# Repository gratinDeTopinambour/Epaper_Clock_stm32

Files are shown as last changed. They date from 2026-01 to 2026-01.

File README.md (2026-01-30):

# Epaper_Clock_display

A silent, light-free bedside clock built with:

- **STM32F103C** (“Blue Pill”)
- **ESP-01** (Wi‑Fi)
- **3.52" e-paper HAT (B)**
- **BME280** (temperature, humidity, pressure sensor)

No display backlight, no ticking noise – ideal to keep next to your bed without disturbing sleep.

---

## Features

- **Always-readable e-paper display**
  - Time and date
  - Temperature, humidity (BME280)
- **Low light pollution**
  - E-paper only refreshes when needed
  - No LEDs or backlight by default
- **Wi‑Fi connectivity (ESP‑01)**
  - Intended for time sync
---

## Project Structure

```text
Epaper_Clock_stm32/
├─ 3D_print/                 # Enclosure and mechanical parts
├─ Electronics and schematics/  # Schematics, PCB files, wiring diagrams
└─ Stm32 Code/               # STM32 firmware (CubeIDE project)
```

- **`3D_print/`**  
  Contains all files related to the case/enclosure:
  - STL files for 3D printing

- **`Electronics and schematics/`**  
  Contains all electronics documentation:
  - Schematics
  - gerber

- **`Stm32 Code/`**  
  STM32CubeIDE project implementing:
  - Display update logic
  - Sensor reading (BME280 via I2C)
  - Interface with ESP‑01 (UART)
  - Timer-based refresh (TIM3, 1‑minute interrupt)  
---

## Hardware Overview

- **MCU**: STM32F103C
- **Display**: 3.52" e-paper HAT (B)
- **Wi‑Fi module**: ESP‑01
- **Sensor**: BME280
- **Power**: 5 V input (e.g. USB), with on-board regulation to 3.3 V for logic

---

## Getting Started

1. **Print the enclosure**  
   - Open `3D_print/` and print the parts

2. **Build the electronics**  
   - Use the schematics and wiring diagrams from `Electronics and schematics/`.

3. **Flash the STM32 firmware**
   - Open the project in **STM32CubeIDE** from the `Stm32 Code/` folder.
   - Check that the pin configuration matches your STM32 variant and board.
   - Build and flash using an ST‑Link.

4. **Assemble the clock**
   - Mount the boards and e‑paper into the printed enclosure.
   - Route cables and ensure no strain on connectors.
   - Close the enclosure.

---

## Future Improvements / Ideas

- Meteo information
- Battery backup

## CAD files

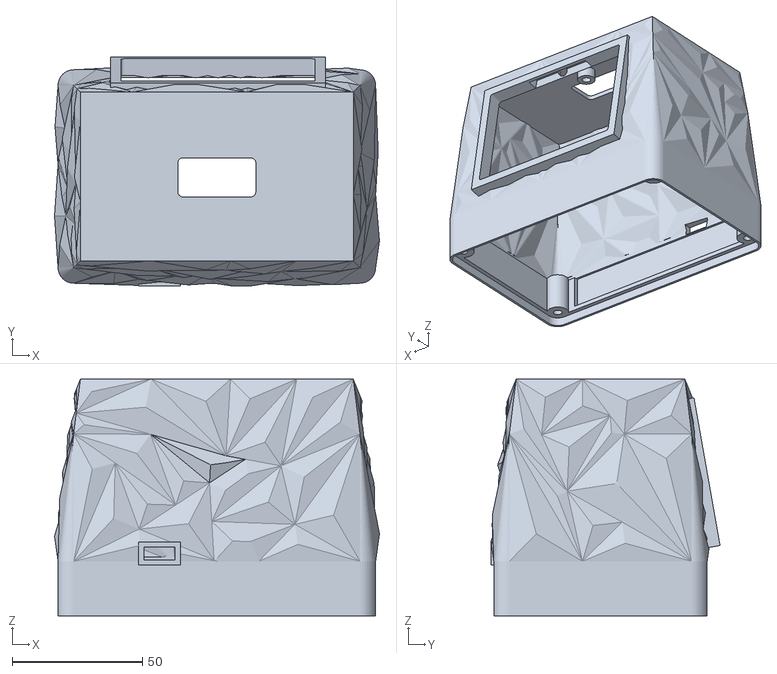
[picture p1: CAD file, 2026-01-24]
3D_print/top_reveil.stl
124.8 x 88.0 x 91.0

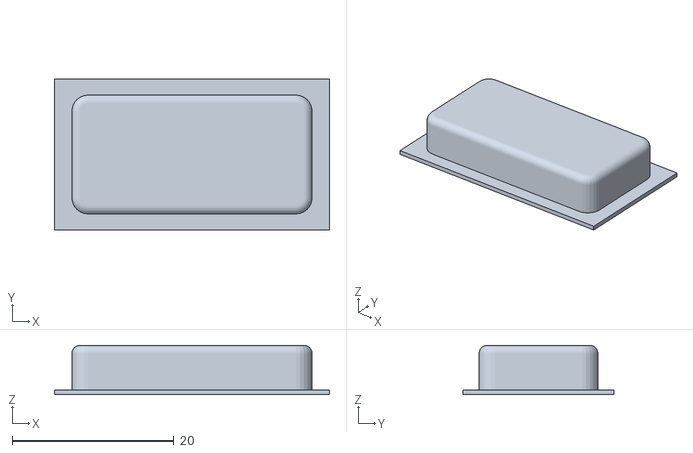
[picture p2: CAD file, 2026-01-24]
3D_print/switch_display.stl
34.0 x 18.7 x 6.10

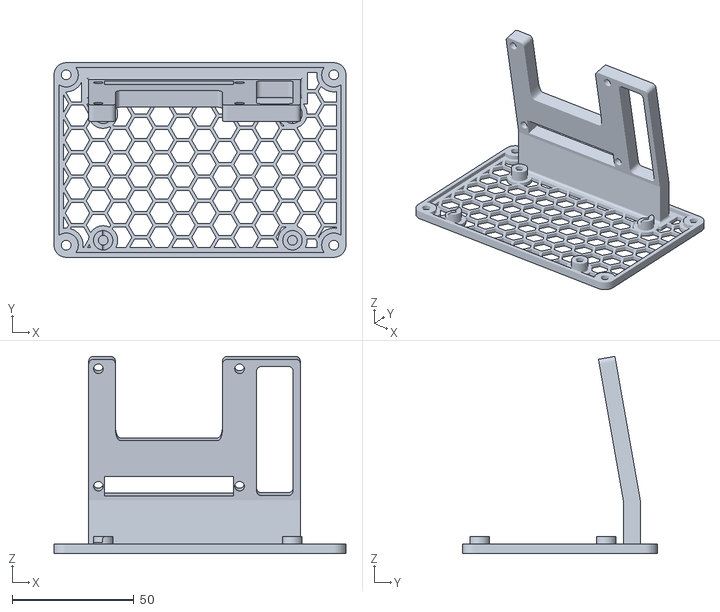
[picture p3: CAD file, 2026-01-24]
3D_print/base_reveil_v2.stl
120.0 x 80.0 x 81.1

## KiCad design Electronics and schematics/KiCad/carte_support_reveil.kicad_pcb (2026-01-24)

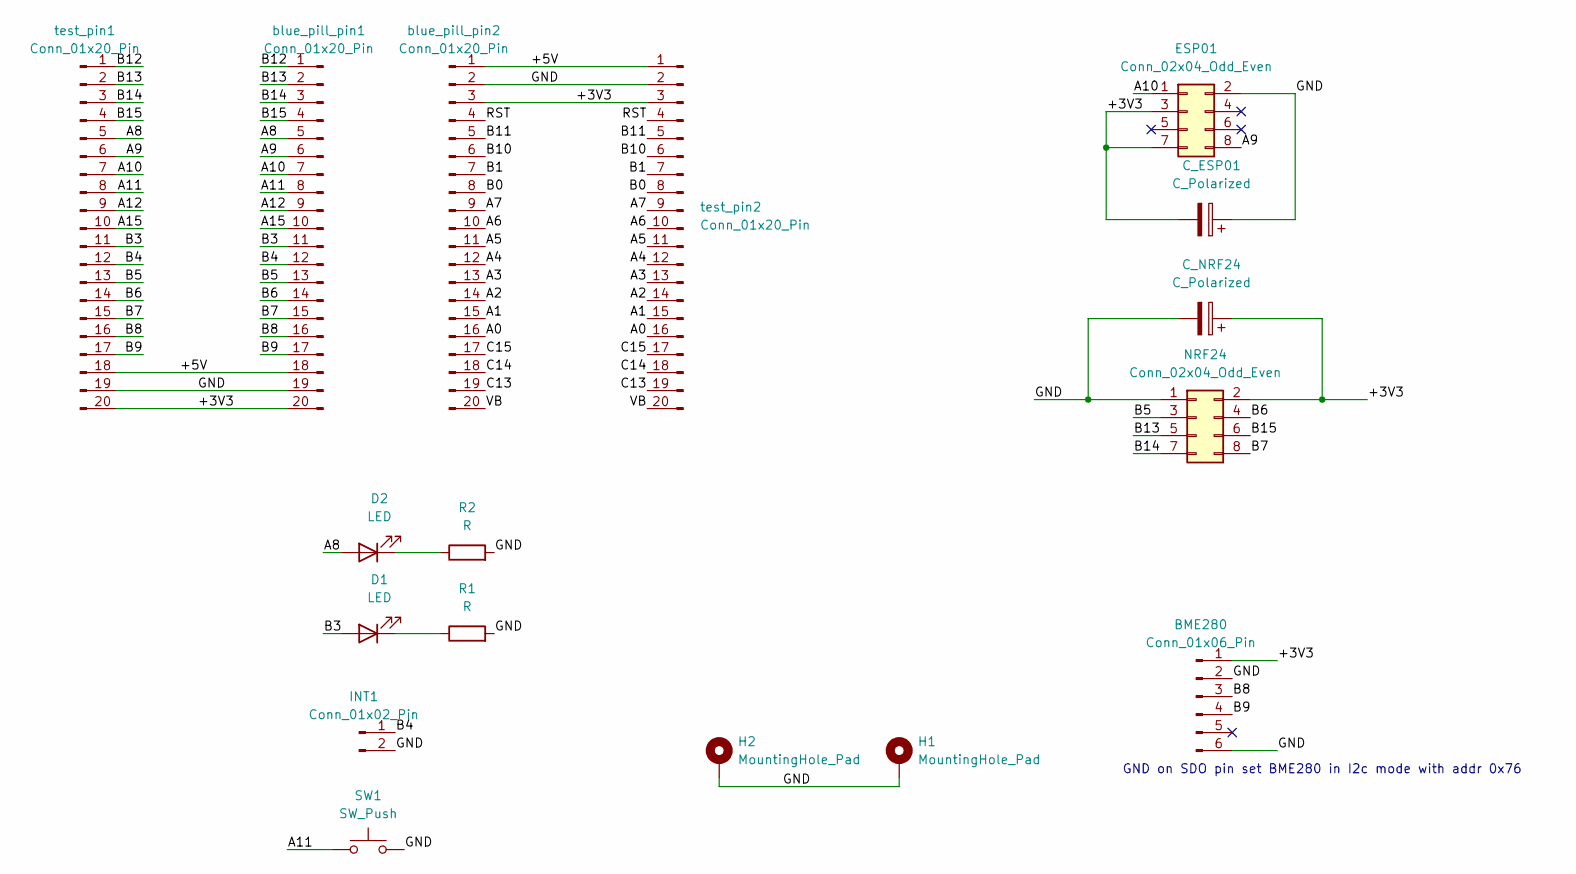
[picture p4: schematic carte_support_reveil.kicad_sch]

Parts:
BME280: Conn_01x06_Pin; PinHeader_1x06_P2.54mm_Vertical
C_ESP01: C_Polarized; C_Radial_D6.3mm_H11.0mm_P2.50mm
C_NRF24: C_Polarized; C_Radial_D6.3mm_H11.0mm_P2.50mm
D1, D2: LED; LED_D5.0mm
ESP01: Conn_02x04_Odd_Even; PinHeader_2x04_P2.54mm_Vertical
H1, H2: MountingHole_Pad; MountingHole_3.2mm_M3_Pad_Via
INT1: Conn_01x02_Pin; PinHeader_1x02_P2.54mm_Vertical
NRF24: Conn_02x04_Odd_Even; PinHeader_2x04_P2.54mm_Vertical
R1, R2: R; R_Axial_DIN0411_L9.9mm_D3.6mm_P15.24mm_Horizontal
SW1: SW_Push; SW_PUSH_6mm_H5mm
blue_pill_pin1, blue_pill_pin2: Conn_01x20_Pin; PinHeader_1x20_P2.54mm_Vertical
test_pin1, test_pin2: Conn_01x20_Pin; PinHeader_1x20_P2.54mm_Vertical

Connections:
/+3V3: BME280.1, C_ESP01.2, C_NRF24.1, ESP01.3, ESP01.7, NRF24.2, blue_pill_pin1.20, blue_pill_pin2.3, test_pin1.20, test_pin2.3
/+5V: blue_pill_pin1.18, blue_pill_pin2.1, test_pin1.18, test_pin2.1
/A0: blue_pill_pin2.16, test_pin2.16
/A1: blue_pill_pin2.15, test_pin2.15
/A2: blue_pill_pin2.14, test_pin2.14
/A3: blue_pill_pin2.13, test_pin2.13
/A4: blue_pill_pin2.12, test_pin2.12
/A5: blue_pill_pin2.11, test_pin2.11
/A6: blue_pill_pin2.10, test_pin2.10
/A7: blue_pill_pin2.9, test_pin2.9
/A8: D2.2 (A), blue_pill_pin1.5, test_pin1.5
/A9: ESP01.8, blue_pill_pin1.6, test_pin1.6
/A10: ESP01.1, blue_pill_pin1.7, test_pin1.7
/A11: SW1.1, blue_pill_pin1.8, test_pin1.8
/A12: blue_pill_pin1.9, test_pin1.9
/A15: blue_pill_pin1.10, test_pin1.10
/B0: blue_pill_pin2.8, test_pin2.8
/B1: blue_pill_pin2.7, test_pin2.7
/B3: D1.2 (A), blue_pill_pin1.11, test_pin1.11
/B4: INT1.1, blue_pill_pin1.12, test_pin1.12
/B5: NRF24.3, blue_pill_pin1.13, test_pin1.13
/B6: NRF24.4, blue_pill_pin1.14, test_pin1.14
/B7: NRF24.8, blue_pill_pin1.15, test_pin1.15
/B8: BME280.3, blue_pill_pin1.16, test_pin1.16
/B9: BME280.4, blue_pill_pin1.17, test_pin1.17
/B10: blue_pill_pin2.6, test_pin2.6
/B11: blue_pill_pin2.5, test_pin2.5
/B12: blue_pill_pin1.1, test_pin1.1
/B13: NRF24.5, blue_pill_pin1.2, test_pin1.2
/B14: NRF24.7, blue_pill_pin1.3, test_pin1.3
/B15: NRF24.6, blue_pill_pin1.4, test_pin1.4
/C13: blue_pill_pin2.19, test_pin2.19
/C14: blue_pill_pin2.18, test_pin2.18
/C15: blue_pill_pin2.17, test_pin2.17
/GND: BME280.2, BME280.6, C_ESP01.1, C_NRF24.2, ESP01.2, H1.1, H2.1, INT1.2, NRF24.1, R1.2, R2.2, SW1.2, blue_pill_pin1.19, blue_pill_pin2.2, test_pin1.19, test_pin2.2
/RST: blue_pill_pin2.4, test_pin2.4
/VB: blue_pill_pin2.20, test_pin2.20
unnamed: D1.1 (K), R1.1
unnamed: D2.1 (K), R2.1

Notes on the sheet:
GND on SDO pin set BME280 in I2c mode with addr 0x76

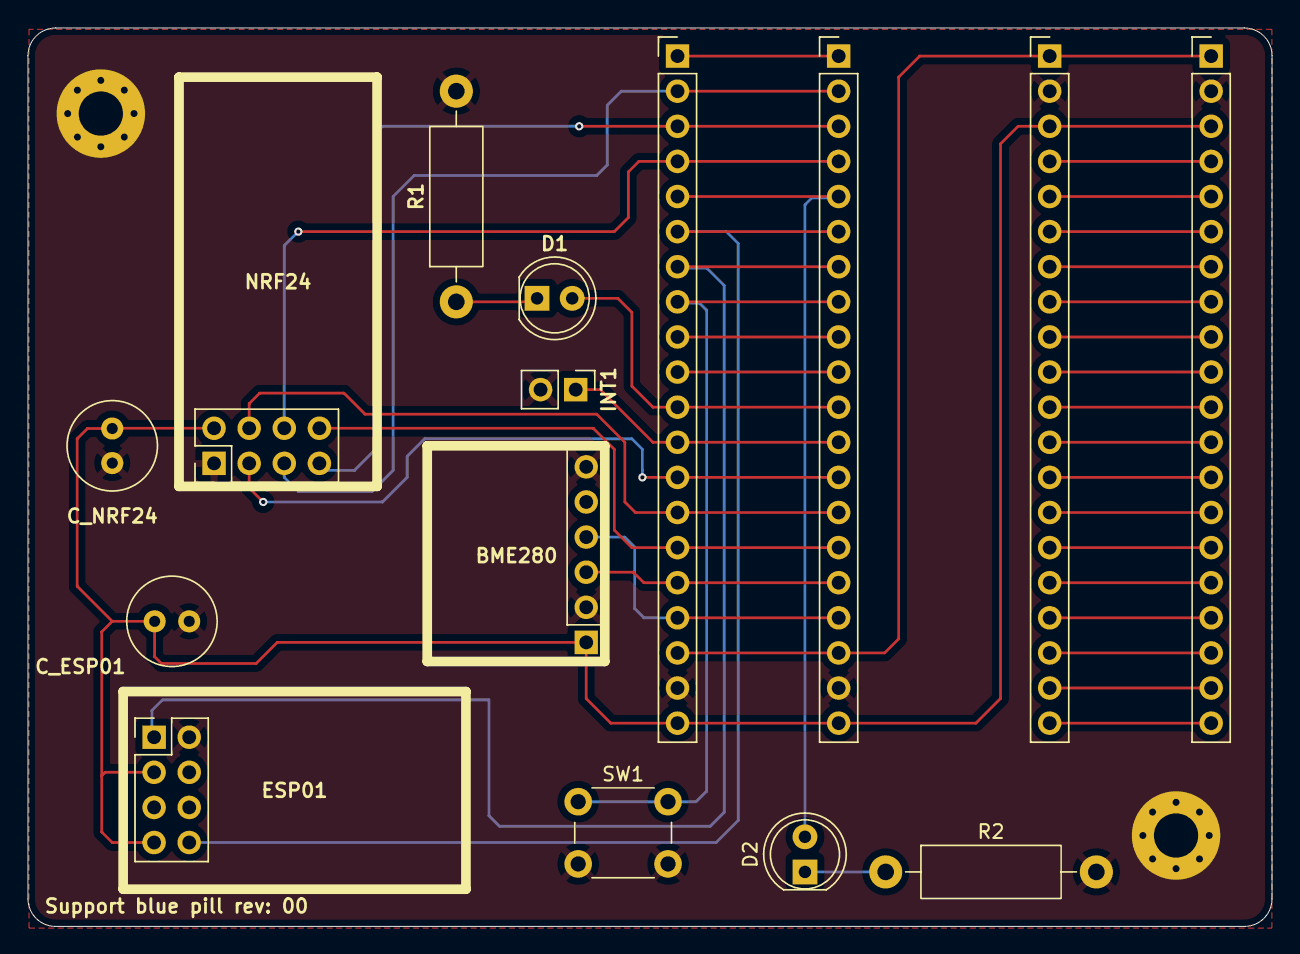
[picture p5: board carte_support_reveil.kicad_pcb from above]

Board: 2 copper layers, 90.0 x 65.0 mm, 17 parts (0 on the bottom side), 39 nets.

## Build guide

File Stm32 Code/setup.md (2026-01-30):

# STM32 Hardware & CubeIDE Setup

## Hardware Connections

### ESP-01 (UART1)
**USART1 (to ESP-01)**
- PA9  – TX  
- PA10 – RX  

---

### PC Communication & Debug (UART2)
**USART2 (to USB-UART / PC)**
- PA2 – TX  
- PA3 – RX  

---

### BME280 (I2C)
**I2C (BME280 sensor)**
- PB9 – SDA  
- PB8 – SCL  

---

### E-Paper Module (SPI1 + GPIO)
**SPI1**
- PA5 – SCK  
- PA7 – MOSI / DIN  

**Control pins (GPIO output)**
- PA1 – RST  
- PA4 – SPI_CS  
- PA6 – DC  

**Status pin (GPIO input)**
- PA0 – BUSY  

---

## STM32CubeIDE Configuration

> Adjust pin names if your MCU variant differs.

### TIM3 (Periodic Interrupt Every Minute)
- Clock source: **Internal Clock**
- (Example) APB clock: **48 MHz**
- Prescaler: **47999**  
- Counter Period: **59999**  
- Interrupt: **Enabled**

This configuration (48 MHz / (47999 + 1) / (59999 + 1)) ≈ 1 Hz / 60 → 1 interrupt per minute.  
Adapt `Prescaler` and `Counter Period` to your own clock if different.

---

### USART1 (ESP-01)
- Mode: **Asynchronous**
- Baud rate: **115200**
- DMA: **Enabled on UART_RX** in **circular** mode

---

### USART2 (PC / Debug)
- Mode: **Asynchronous**
- Baud rate: **115200**

---

### I2C (BME280)
- Mode: **I2C**
- Configure speed (Standard/Fast) as needed by your application and wiring.

---

### SPI1 (E-Paper)
- Mode: **Transmit Only Master**
- Data size: **8 bits**
- Bit order: **MSB First**
- Prescaler: **256** (maximum, for a low SPI speed)
- Clock polarity (CPOL): **Low**
- Clock phase (CPHA): **1 Edge**

---

### GPIO
**Outputs (RST, SPI_CS, DC, etc.)**
- Mode: **Output**
- Output type: **Push-Pull**

**Inputs (BUSY)**
- Mode: **Input**
- Pull-up / Pull-down: configure as required by your e-paper module (often no pull, check datasheet).

---

## Code Modifications

File: `stm32f0xx_it.c`  
(Use the corresponding interrupt file for your STM32 series, e.g. `stm32f1xx_it.c`, `stm32l4xx_it.c`, etc.)

### 1. Declare the `minute` Variable

At the top of the file, in the **private variables** section, add:

```c
extern uint16_t minute;
```

 2. Increment `minute` in the TIM3 Interrupt

Inside `TIM3_IRQHandler` (or `TIM3_IRQHandler(void)`), add:

```c
void TIM3_IRQHandler(void)
{
  /* USER CODE BEGIN TIM3_IRQn 0 */
  minute++;
  /* USER CODE END TIM3_IRQn 0 */

  HAL_TIM_IRQHandler(&htim3);
}
```

Make sure the increment is inside the `USER CODE` section so it is not overwritten by code generation.

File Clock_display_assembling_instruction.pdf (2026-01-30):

# Epaper Clock Display

Assembling instruction

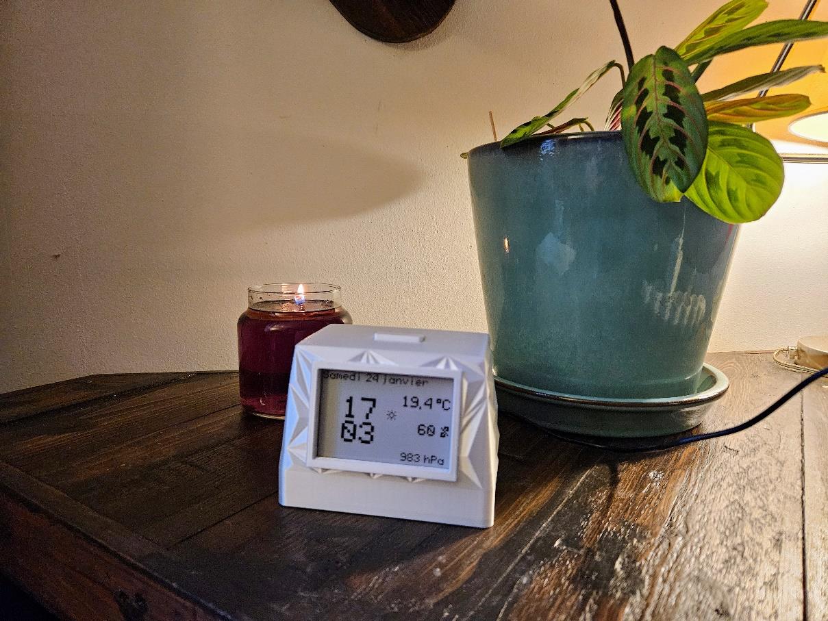
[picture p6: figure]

### @topinambour

30/01/2026

P a g e 1 | 9

## Table of content

P a g e 2 | 9

## 1 Bill of Materials

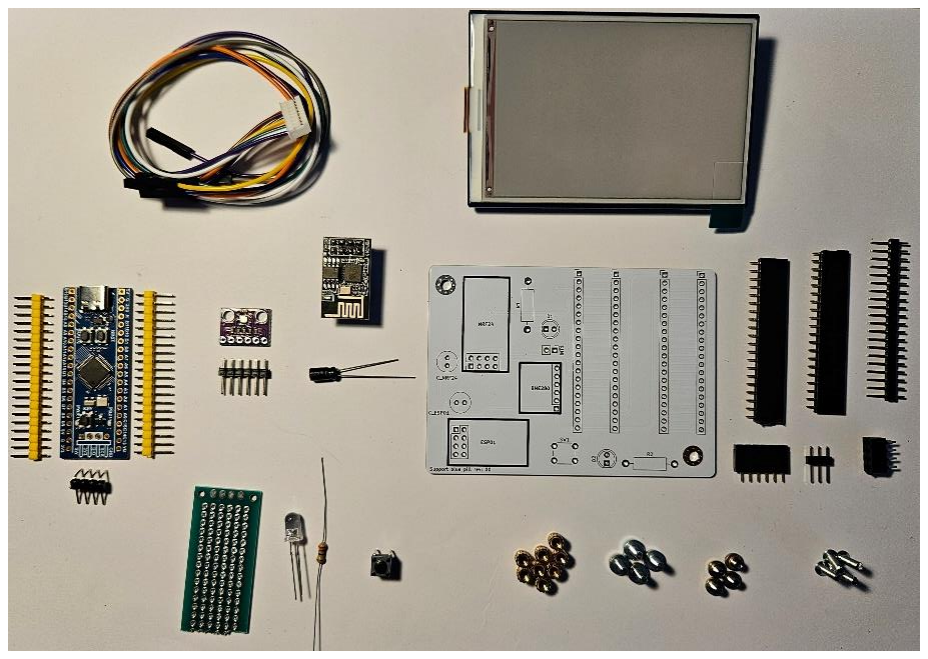
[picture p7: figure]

### 1.1 Electronics

- EPAPER Display: 3.52‑inch e‑Paper display (B), e‑ink, 360×240, Red/Black/White, SPI interface
- STM32: WeAct Studio STM32F103CBT6 Bluepill Plus (ARM STM32)
- BME280 sensor, 3.3 V, SPI/I²C
- ESP‑01S Wi‑Fi module
- 10 µF capacitor
- PCB / Board from:
https://github.com/gratinDeTopinambour/Epaper_Clock_stm32/tree/75e67bf902ec7e3da256f629115687a51065c9e0/Electronics%20and%20schematics (https://github.com/gratinDeTopinambour/Epaper_Clock_stm32/tree/75e67bf902ec7e3da256f629115687a51065c9e0/Electronics%20and%20schematics)

### 1.2 Connectors (2.54mm pitch

- 2 × 20‑pin female header, 2.54 mm
- 1 × 20‑pin male header, 2.54 mm
- 1 × 3‑pin male header, 2.54 mm
- 1 × 6‑pin female header, 2.54 mm
- 1 × 4×2‑pin (8‑pin) female header, 2.54 mm

### 1.3 Light and switch

- 6×6×5 mm push button switch
- 5 mm LED (max 3 V)
- Resistor (LED series resistor, value as per schematic)
- Test board / prototyping board

### 1.4 Fasteners & Mechanical Parts

- 8 × threaded inserts: 3DZWMAN D4.6, L5.7, d3.9, M3
- 8 × M3 screws
- 4 × M2.5 screws (for the display)

P a g e 3 | 9

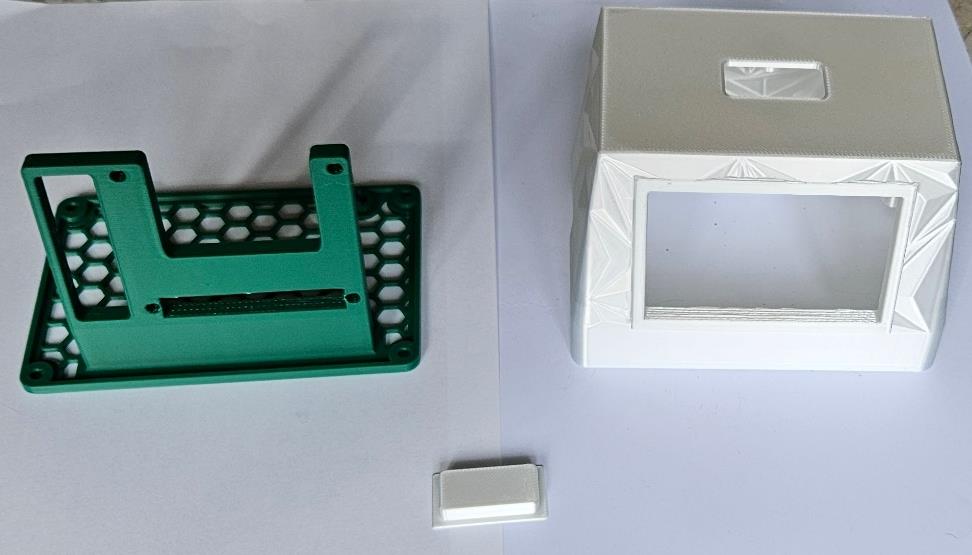
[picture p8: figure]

### 1.5 3D‑Printed Parts

https://github.com/gratinDeTopinambour/Epaper_Clock_stm32/tree/75e67bf902ec7e3da256f629115687a51065c9e0/3D_print (https://github.com/gratinDeTopinambour/Epaper_Clock_stm32/tree/75e67bf902ec7e3da256f629115687a51065c9e0/3D_print)

- 1 × 3D‑printed switch holder
- 1 × 3D‑printed top cover
- 1 × 3D‑printed bottom cover

## 2 Assembling Instruction

### 2.1 Soldering on the PCB

- Solder all connectors (headers) in their corresponding positions on the PCB.
- Solder the 10 µF capacitor at position C_ESP01.

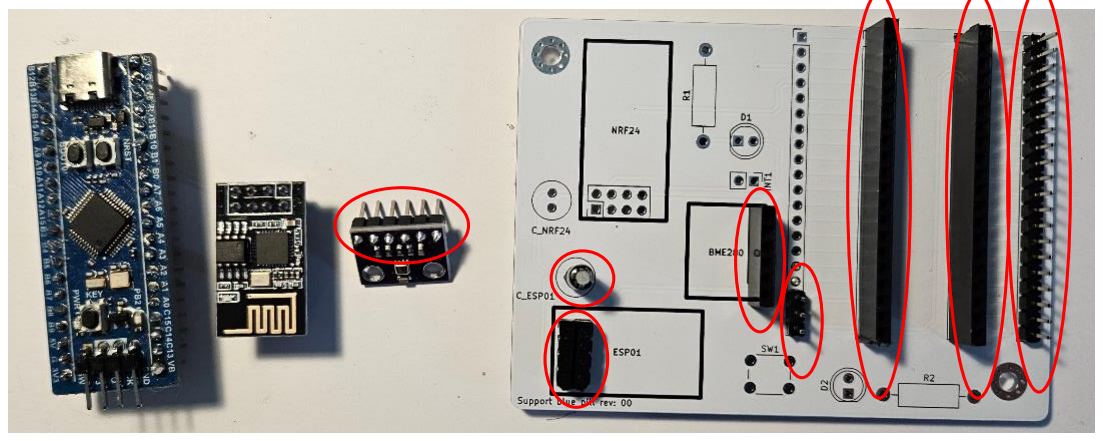
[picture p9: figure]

### 2.2 Plug-in Modules

- Insert the BME280 module in its designated connector.
- Insert the ESP‑01 module in its designated connector.
- Insert the STM32 (WeAct Bluepill Plus) into its 20‑pin female headers.

P a g e 4 | 9

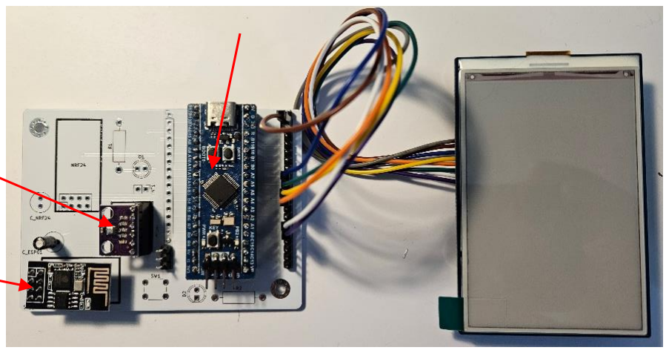
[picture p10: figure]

### 2.3 Connect the e‑Paper Display

Wire the e‑Paper connector to the STM32 as follows:

- EPD BUSY → PA0
- EPD RST → PA1
- EPD CS (chip select) → PA4
- EPD SCK / CLK → PA5
- EPD DC (data/command) → PA6
- EPD MOSI / DIN → PA7
- EPD GND → GND
- EPD VCC / VDD → 3.3 V

### 2.4 Programming and configuration instructions

- Use an ST-Link to connect the STM32 board to your computer.
- Open the project in STM32CubeIDE.
- In main.c, replace all instances of
- Init_Wifi("Wifi_name", "Wifi_pswd");
- with your own Wi-Fi name (SSID) and password.
- Program (flash) the STM32 board with the code.
- After flashing, check that the e-paper display shows the correct date and time.
- If the display does not show the correct information, there may be a Wi-Fi connection problem.
- Try pressing the reset button on the STM32 board—this may resolve the issue.

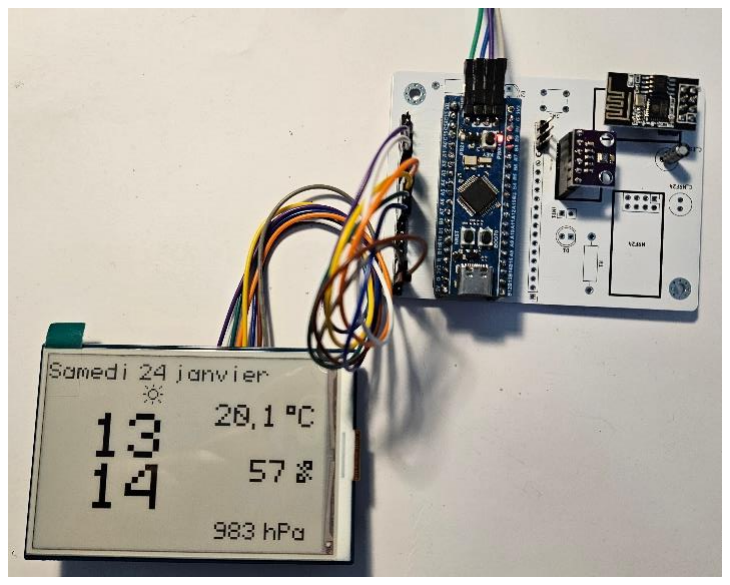
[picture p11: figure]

P a g e 5 | 9

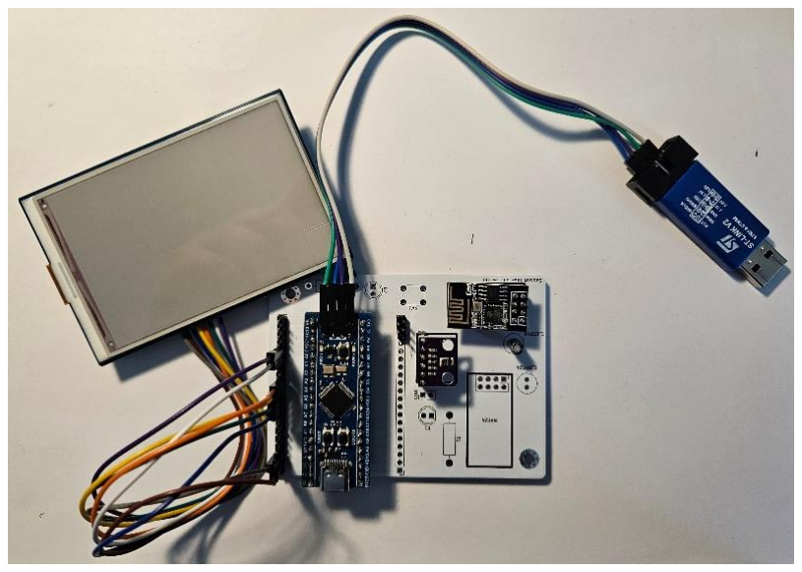
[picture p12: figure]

### 2.5 Light switch

2.5.1 Preliminary Functional Test
- Power up the assembled PCB and let it display the hour information.
- Observe the display for a period of time to ensure it functions correctly and does not exhibit any glitches before proceeding with final assembly.

2.5.2 Switch and LED Test Board Assembly
- While the board is running, prepare a small prototype (test) board at least 35 mm wide.

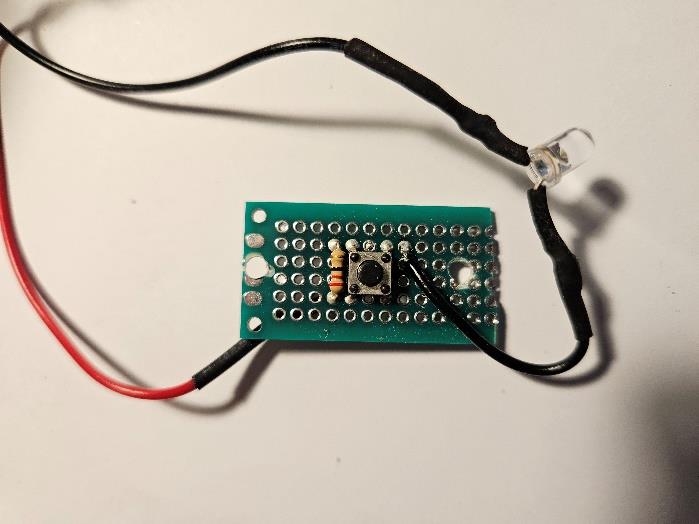
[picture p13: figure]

- Mount the Components:
a. Solder the push button switches at the center of the test board.
b. Connect a resistor in series with the switch.
Calculate the resistor value with:
R > (3.3 V – LED_Voltage) / LED_max_current
For a typical white LED:
LED_Voltage ≈ 3 V
LED_max_current ≈ 20 mA (0.02 A) Suggested resistor value: about 100 Ω
- Wire Connections:

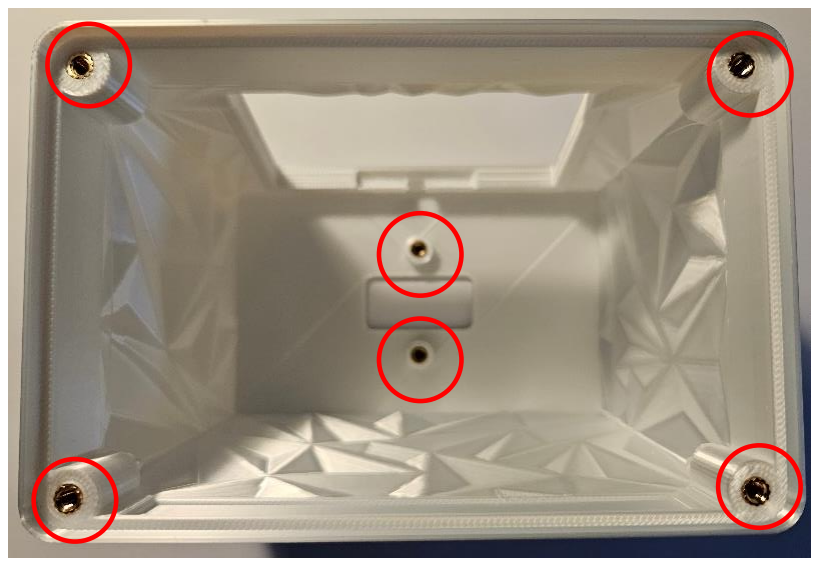
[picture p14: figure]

P a g e 6 | 9
a. Solder a wire (about 10 cm long) to one leg of the switch; this will connect to the 3.3 V supply.
b. On the other side of the resistor, solder a second wire (about 4 cm long) for the LED connection.
c. Connect the anode (longer leg) of the LED to this 4 cm wire.
d. Connect the cathode (shorter leg, flat side) of the LED to another 10 cm wire, which will connect to ground.
e. Important: Ensure correct polarity—do not swap the LED’s anode and cathode.

### 2.6 Assembly

2.6.1 Insert Fixings
- Place all threaded inserts into their corresponding holes in the 3D-printed parts. Use a soldering iron or a heated tool if needed to set the inserts securely.

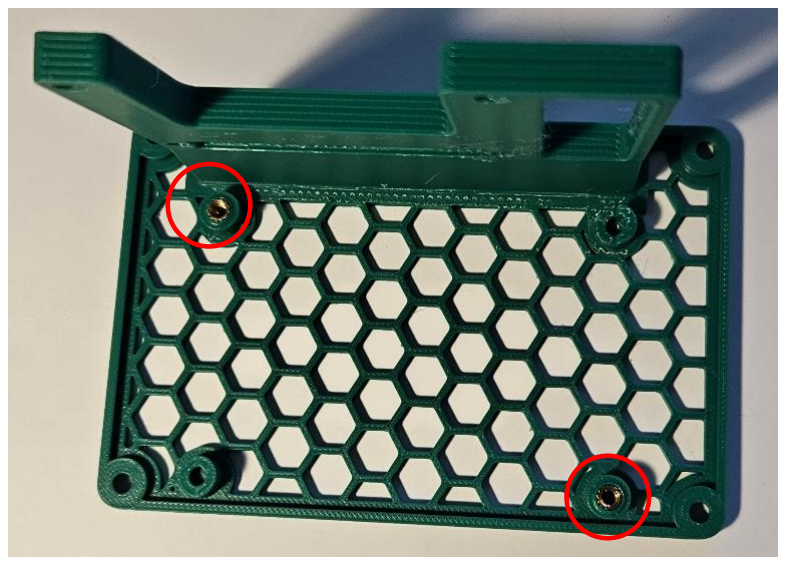
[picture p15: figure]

2.6.2 Mount the E-paper Display
- Align the e-paper display with the front panel.
- Screw the display onto the front panel.

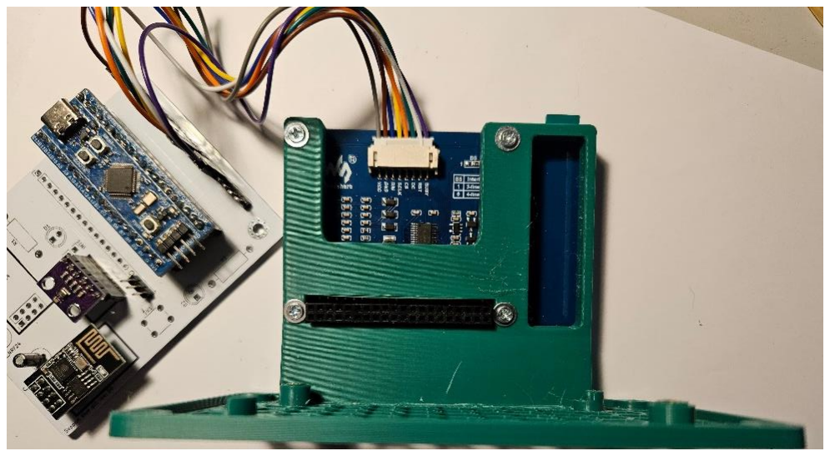
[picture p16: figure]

2.6.3 Mount the PCB
- Place the assembled PCB onto the bottom section of the enclosure.

P a g e 7 | 9
- Screw the board to the bottom panel.

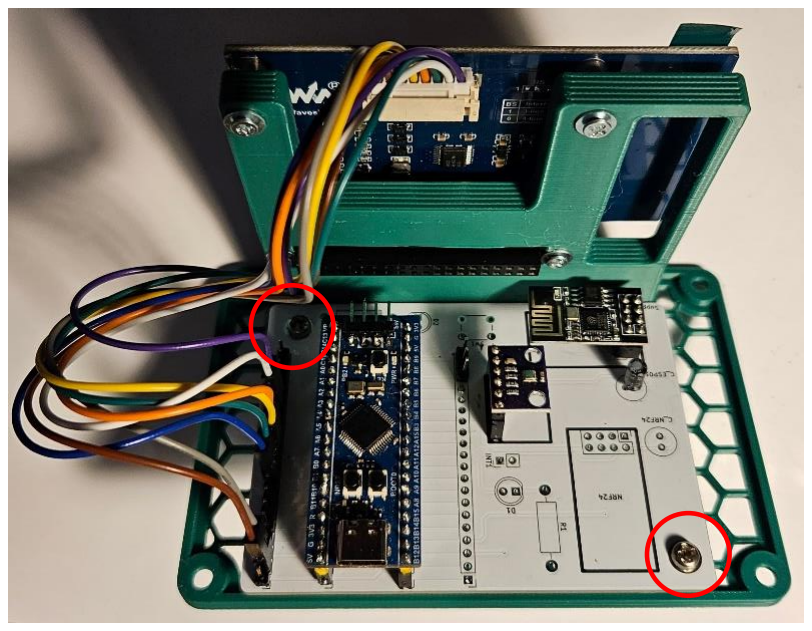
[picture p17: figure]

2.6.4 Prepare the Button Board
- Mark and drill two holes on the button board so they align with the inserts on the inside of the top 3D-printed shell.

2.6.5 Install the 3D-printed Switch Cap
- Fit the 3D-printed switch cap into position.
- Screw the button board in place to secure the switch. Make sure the button is centered on the switch.

2.6.6 LED Placement
- Insert the LED into the 5 mm hole on top of the display area of the enclosure.

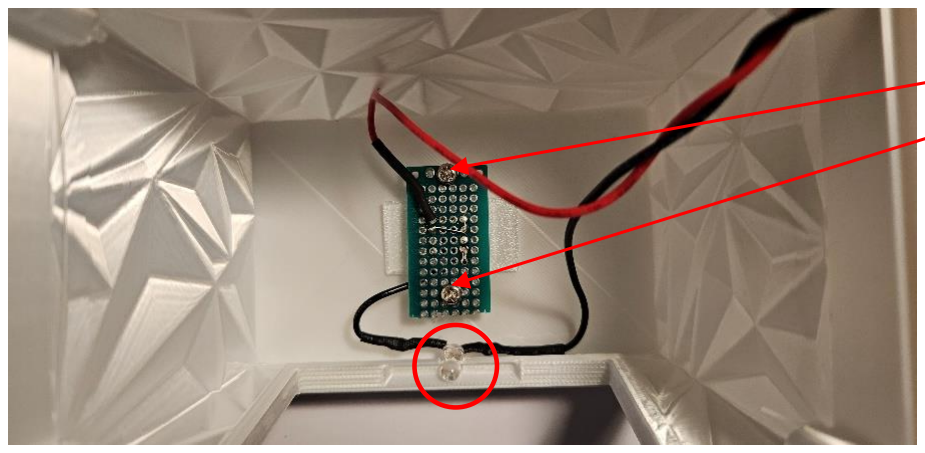
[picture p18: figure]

2.6.7 Wire Connections
- Connect the switch wire to the 3.3V main power line.
- Connect the LED wire to ground.
- Test the LED with power applied to ensure correct polarity—if it does not light, reverse the LED wiring.

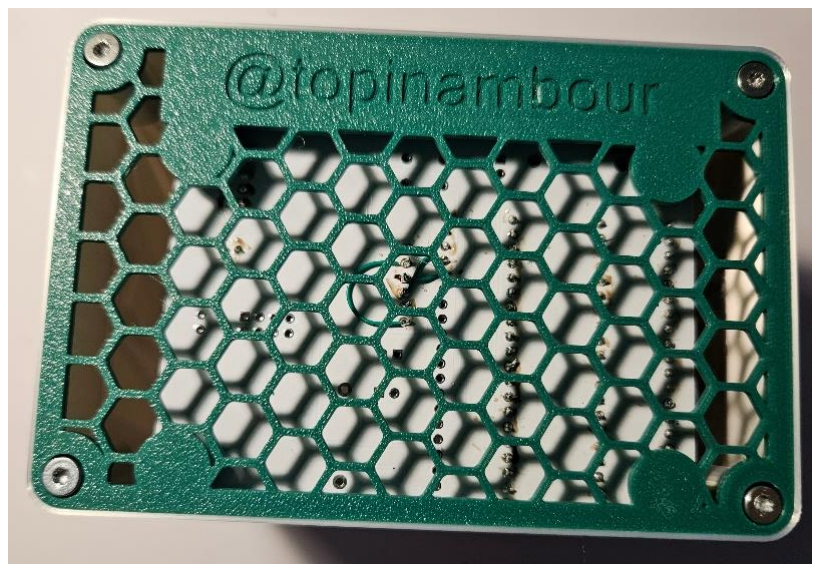
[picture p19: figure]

P a g e 8 | 9

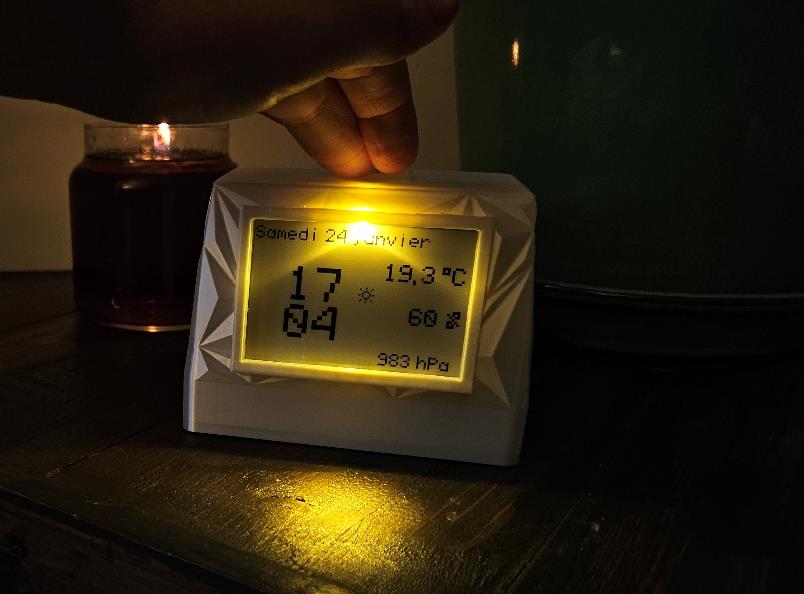
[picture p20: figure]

2.6.8 Enclosure Assembly
- Place the top part of the 3D-printed enclosure onto the bottom.
- Secure enclosure parts by screwing them together

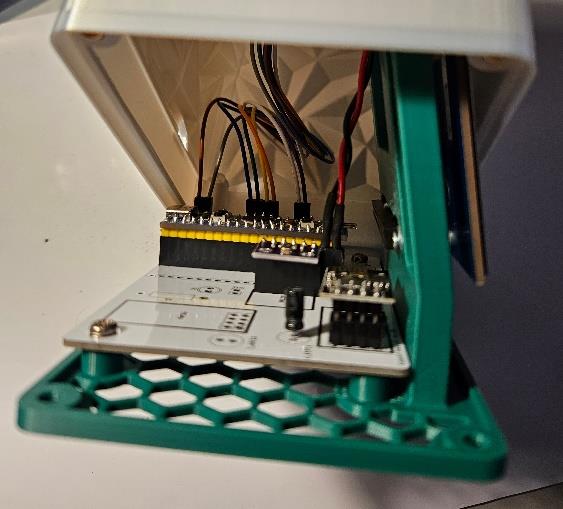
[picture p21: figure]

2.6.9 Final Check
- Power up the assembly and confirm the e-paper display works correctly, displaying the desired information.
- Verify that the LED and switch function as expected.

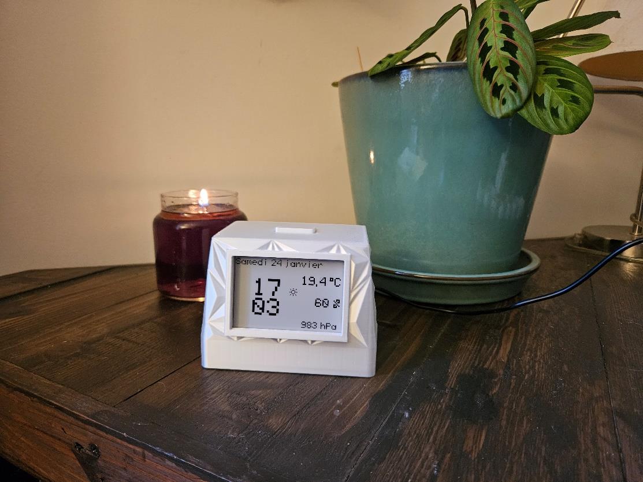
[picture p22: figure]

P a g e 9 | 9

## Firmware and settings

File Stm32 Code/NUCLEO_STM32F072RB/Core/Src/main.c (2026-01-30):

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
/* Includes ------------------------------------------------------------------*/
#include "main.h"

/* USER CODE BEGIN Includes */

#include <stdio.h>
#include <stdlib.h> // malloc() free()
#include <string.h>
#include "ESP01_HAL.h"
#include "date_converter.h"
#include "DRIVER.h"
#include "EPAPER.h"
#include "bme280.h"

/* USER CODE END Includes */

I2C_HandleTypeDef hi2c1;

SPI_HandleTypeDef hspi1;

TIM_HandleTypeDef htim3;

UART_HandleTypeDef huart1;
UART_HandleTypeDef huart2;
DMA_HandleTypeDef hdma_usart1_rx;

/* USER CODE BEGIN PV */
uint8_t dma_rx_buf[1024]; // Buffer DMA pour la réception ESP01
/* USER CODE END PV */

void SystemClock_Config(void);
static void MX_GPIO_Init(void);
static void MX_DMA_Init(void);
static void MX_USART2_UART_Init(void);
static void MX_USART1_UART_Init(void);
static void MX_SPI1_Init(void);
static void MX_TIM3_Init(void);
static void MX_I2C1_Init(void);
/* USER CODE BEGIN 0 */
uint8_t day = 0;
uint8_t prev_day = 0;
uint8_t dd = 0;
uint8_t mm = 0;
uint16_t yy = 0;
uint16_t minute = 0;
uint16_t prev_minute = 0;
uint8_t moon_phase = 0;

int temp = 0;
int prev_temp = 0;
uint32_t press = 0;
uint32_t prev_press = 0;
uint32_t hum = 0;
uint32_t prev_hum = 0;

uint8_t wifi_update_done = 0;
/* USER CODE END 0 */

/**
  * @brief  The application entry point.
  * @retval int
  */
int main(void)
{

  /* MCU Configuration--------------------------------------------------------*/

  /* Reset of all peripherals, Initializes the Flash interface and the Systick. */
  HAL_Init();

  /* Configure the system clock */
  SystemClock_Config();

  /* Initialize all configured peripherals */
  MX_GPIO_Init();
  MX_DMA_Init();
  MX_USART2_UART_Init();
  MX_USART1_UART_Init();
  MX_SPI1_Init();
  MX_TIM3_Init();
  MX_I2C1_Init();
  /* USER CODE BEGIN 2 */

  if (HAL_TIM_Base_Start_IT(&htim3) != HAL_OK)
  {
    /* Starting Error */
    Error_Handler();
  }
  BME_Init();
  BME_Read_Data(&temp, &press, &hum);

  Init_Wifi("Wifi_name", "Wifi_pswd");
  if(Get_Date(&day, &dd, &mm, &yy, &minute) == 0){
	UTC_to_Paris(&day, &dd, &mm, &yy, &minute);
  }
  prev_minute = minute + 1111;

  moon_phase = Moon_Phase(dd,mm,yy);

  EPAPER_Init();
  EPAPER_Clear();
  HAL_Delay(500);
  EPAPER_Part_Init();
  EPAPER_KW_White_Display();
  HAL_Delay(500);

  EPAPER_Print_temp(temp);
  EPAPER_Print_press(press);
  EPAPER_Print_hum(hum);
  EPAPER_Print_Date(day,  dd, mm);
  EPAPER_Print_Hour(minute,  prev_minute);
  EPAPER_Print_Moon_Phase(moon_phase, minute, 360, 1080);

  prev_minute = minute;
  prev_day = day;
  prev_temp = temp;
  prev_hum = hum;
  prev_press = press;
  /* USER CODE END 2 */

  /* Infinite loop */
  /* USER CODE BEGIN WHILE */
  while (1)
  {


	if(prev_minute != minute)
	{
		if(minute >= 1440){
			minute = 0;
			day++;
		}

		EPAPER_Print_Hour(minute,  prev_minute);
		EPAPER_Print_Moon_Phase(moon_phase, minute, 360, 1080);
		prev_minute = minute;

		/* update temp hum and press each minute */
		BME_Read_Data(&temp, &press, &hum);

		if(prev_temp != temp){
			prev_temp = temp;
			EPAPER_Print_temp(temp);
		}
		if(prev_press != press){
			prev_press = press;
			EPAPER_Print_press(press);
		}
		if(prev_hum != hum){
			prev_hum = hum;
			EPAPER_Print_hum(hum);
		}
	}

	if(prev_day != day)
	{
		if(day >= 7){
			day = 0;
		}
		prev_day = day;

		next_day(&dd,&mm,&yy);

		EPAPER_Print_Date(day,  dd, mm);
		moon_phase = Moon_Phase(dd,mm,yy);
	}

	/* reset screen every day at 4h*/
	if((minute == 240 || minute == 600 || minute == 960 || minute == 1320) && !wifi_update_done){
		wifi_update_done = 1;

		Init_Wifi("Wifi_name", "Wifi_pswd");
		if(Get_Date(&day, &dd, &mm, &yy, &minute) == 0){
			UTC_to_Paris(&day, &dd, &mm, &yy, &minute);
		}
		prev_minute = minute + 1111;

		EPAPER_Init();
		EPAPER_Clear();
		HAL_Delay(500);
		EPAPER_Part_Init();
		EPAPER_KW_White_Display();
		HAL_Delay(500);

		EPAPER_Print_temp(temp);
		EPAPER_Print_press(press);
		EPAPER_Print_hum(hum);
		EPAPER_Print_Date(day,  dd, mm);
		EPAPER_Print_Hour(minute,  prev_minute);
		EPAPER_Print_Moon_Phase(moon_phase, minute, 360, 1080);
		prev_minute = minute;
		prev_day = day;
		prev_temp = temp;
		prev_hum = hum;
		prev_press = press;
	}

	if(minute == 241 || minute == 601 || minute == 961 || minute == 1321){
		wifi_update_done = 0;
	}
    /* USER CODE END WHILE */

    /* USER CODE BEGIN 3 */
  }
  /* USER CODE END 3 */
}

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


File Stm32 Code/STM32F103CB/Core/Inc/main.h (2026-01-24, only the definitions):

#define BUSY_Pin GPIO_PIN_0
#define BUSY_GPIO_Port GPIOA
#define RST_Pin GPIO_PIN_1
#define RST_GPIO_Port GPIOA
#define SPI_CS_Pin GPIO_PIN_4
#define SPI_CS_GPIO_Port GPIOA
#define SCK_Pin GPIO_PIN_5
#define SCK_GPIO_Port GPIOA
#define DC_Pin GPIO_PIN_6
#define DC_GPIO_Port GPIOA
#define DIN_Pin GPIO_PIN_7
#define DIN_GPIO_Port GPIOA

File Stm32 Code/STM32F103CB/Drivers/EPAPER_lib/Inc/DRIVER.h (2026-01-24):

#ifndef _DRIVER_H_
#define _DRIVER_H_

#include "main.h"
#include "stm32f1xx_hal.h"
#include "stm32f1xx_hal_gpio.h"
#include <stdint.h>
#include <stdio.h>

/**
 * e-Paper GPIO
 **/
#define EPAPER_RST_PIN RST_Pin
#define EPAPER_RST_PORT RST_GPIO_Port

#define EPAPER_DC_PIN DC_Pin
#define EPAPER_DC_PORT DC_GPIO_Port

#define EPAPER_CS_PIN SPI_CS_Pin
#define EPAPER_CS_PORT SPI_CS_GPIO_Port

#define EPAPER_BUSY_PIN BUSY_Pin
#define EPAPER_BUSY_PORT BUSY_GPIO_Port

#define EPAPER_MOSI_PIN DIN_Pin
#define EPAPER_MOSI_PORT DIN_GPIO_Port

#define EPAPER_SCLK_PIN SCK_Pin
#define EPAPER_SCLK_PORT SCK_GPIO_Port

void SPI_WriteByte(uint8_t value);
void SPI_Write_nByte(uint8_t *value, uint32_t len);

void EPAPER_GPIO_Init(void);
void EPAPER_GPIO_Exit(void);

void EPAPER_Reset(void);
void EPAPER_SendCommand(uint8_t Reg);
void EPAPER_SendData(uint8_t Data);
void EPAPER_Send_nData(uint8_t *pData, uint32_t Len);
void EPAPER_ReadBusy(void);
#endif

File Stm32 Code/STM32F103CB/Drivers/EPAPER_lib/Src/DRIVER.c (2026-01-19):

#include "DRIVER.h"

extern SPI_HandleTypeDef hspi1;

void SPI_WriteByte(uint8_t value)
{
    HAL_SPI_Transmit(&hspi1, &value, 1, 1000);
}

void SPI_Write_nByte(uint8_t *value, uint32_t len)
{
    HAL_SPI_Transmit(&hspi1, value, len, 1000);
}

void EPAPER_GPIO_Init(void)
{
    HAL_GPIO_WritePin(EPAPER_DC_PORT, EPAPER_DC_PIN, 0);
    HAL_GPIO_WritePin(EPAPER_CS_PORT, EPAPER_CS_PIN, 0);
    HAL_GPIO_WritePin(EPAPER_RST_PORT, EPAPER_RST_PIN, 1);
}

void EPAPER_GPIO_Exit(void)
{
    HAL_GPIO_WritePin(EPAPER_DC_PORT, EPAPER_DC_PIN, 0);
    HAL_GPIO_WritePin(EPAPER_CS_PORT, EPAPER_CS_PIN, 0);
    HAL_GPIO_WritePin(EPAPER_RST_PORT, EPAPER_RST_PIN, 0);
}

/******************************************************************************
function :	Software reset
parameter:
******************************************************************************/
void EPAPER_Reset(void)
{
    HAL_GPIO_WritePin(EPAPER_RST_PORT, EPAPER_RST_PIN, 1);
    HAL_Delay(200);
    HAL_GPIO_WritePin(EPAPER_RST_PORT, EPAPER_RST_PIN, 0);
    HAL_Delay(2);
    HAL_GPIO_WritePin(EPAPER_RST_PORT, EPAPER_RST_PIN, 1);
    HAL_Delay(200);
}

/******************************************************************************
function :	send command
parameter:
     Reg : Command register
******************************************************************************/
void EPAPER_SendCommand(uint8_t Reg)
{
    HAL_GPIO_WritePin(EPAPER_DC_PORT, EPAPER_DC_PIN, 0);
    HAL_GPIO_WritePin(EPAPER_CS_PORT, EPAPER_CS_PIN, 0);
    SPI_WriteByte(Reg);
    HAL_GPIO_WritePin(EPAPER_CS_PORT, EPAPER_CS_PIN, 1);
}

/******************************************************************************
function :	send data
parameter:
    Data : Write data
******************************************************************************/
void EPAPER_SendData(uint8_t Data)
{
    HAL_GPIO_WritePin(EPAPER_DC_PORT, EPAPER_DC_PIN, 1);
    HAL_GPIO_WritePin(EPAPER_CS_PORT, EPAPER_CS_PIN, 0);
    SPI_WriteByte(Data);
    HAL_GPIO_WritePin(EPAPER_CS_PORT, EPAPER_CS_PIN, 1);
}

/******************************************************************************
function :	send multiple data
parameter:
    Data : Write data
    len  : data length

/!\ not working on epaper, each data need to be separate by a CS pulse
******************************************************************************/
void EPAPER_Send_nData(uint8_t *Data, uint32_t len)
{
    HAL_GPIO_WritePin(EPAPER_DC_PORT, EPAPER_DC_PIN, 1);
    HAL_GPIO_WritePin(EPAPER_CS_PORT, EPAPER_CS_PIN, 0);
    SPI_Write_nByte(Data, len);
    HAL_GPIO_WritePin(EPAPER_CS_PORT, EPAPER_CS_PIN, 1);
}

/******************************************************************************
function :	Read Busy
parameter:
******************************************************************************/
void EPAPER_ReadBusy(void)
{
    while (!HAL_GPIO_ReadPin(EPAPER_BUSY_PORT, EPAPER_BUSY_PIN))
    {
        HAL_Delay(20);
    }
    HAL_Delay(200);
}

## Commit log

2026-01-19 Rename .setting/com.st.stm32cube.ide.mcu.sfrview.prefs to STM 32/NUCLEO_STM32F072RB/.setting/com.st.stm32cube.ide.mcu.sfrview.prefs
2026-01-19 Update and rename .setting/language.settings.xml to Stm32 Code/NUCLEO_STM32F072RB/.setting/language.settings.xml
2026-01-19 Update and rename .setting/org.eclipse.core.resources.prefs to Stm32 Code/NUCLEO_STM32F072RB/.setting/org.eclipse.core.resources.prefs
2026-01-19 Update and rename .setting/stm32cubeide.project.prefs to Stm32 Code/NUCLEO_STM32F072RB/.setting/stm32cubeide.project.prefs
2026-01-24 Rename Stm32 Code/NUCLEO_STM32F072RB/STM32F103CB/STM32F103CBTX_FLASH.ld to Stm32 Code/STM32F103CB/STM32F103CBTX_FLASH.ld
2026-01-24 Update and rename Stm32 Code/NUCLEO_STM32F072RB/STM32F103CB/clock_display.ioc to Stm32 Code/STM32F103CB/clock_display.ioc

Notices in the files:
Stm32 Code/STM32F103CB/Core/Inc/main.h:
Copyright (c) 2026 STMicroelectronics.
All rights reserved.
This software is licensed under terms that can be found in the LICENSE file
